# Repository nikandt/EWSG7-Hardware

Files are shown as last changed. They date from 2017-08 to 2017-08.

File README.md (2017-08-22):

# PP7 Hardware

This is the hardware repository of sensor probe test module, developed by student team with Aalto University.
<br>The designed system automates several tedious tasks within sensor application development by allowing easy flashing of devices without making physical changes to the test environment.

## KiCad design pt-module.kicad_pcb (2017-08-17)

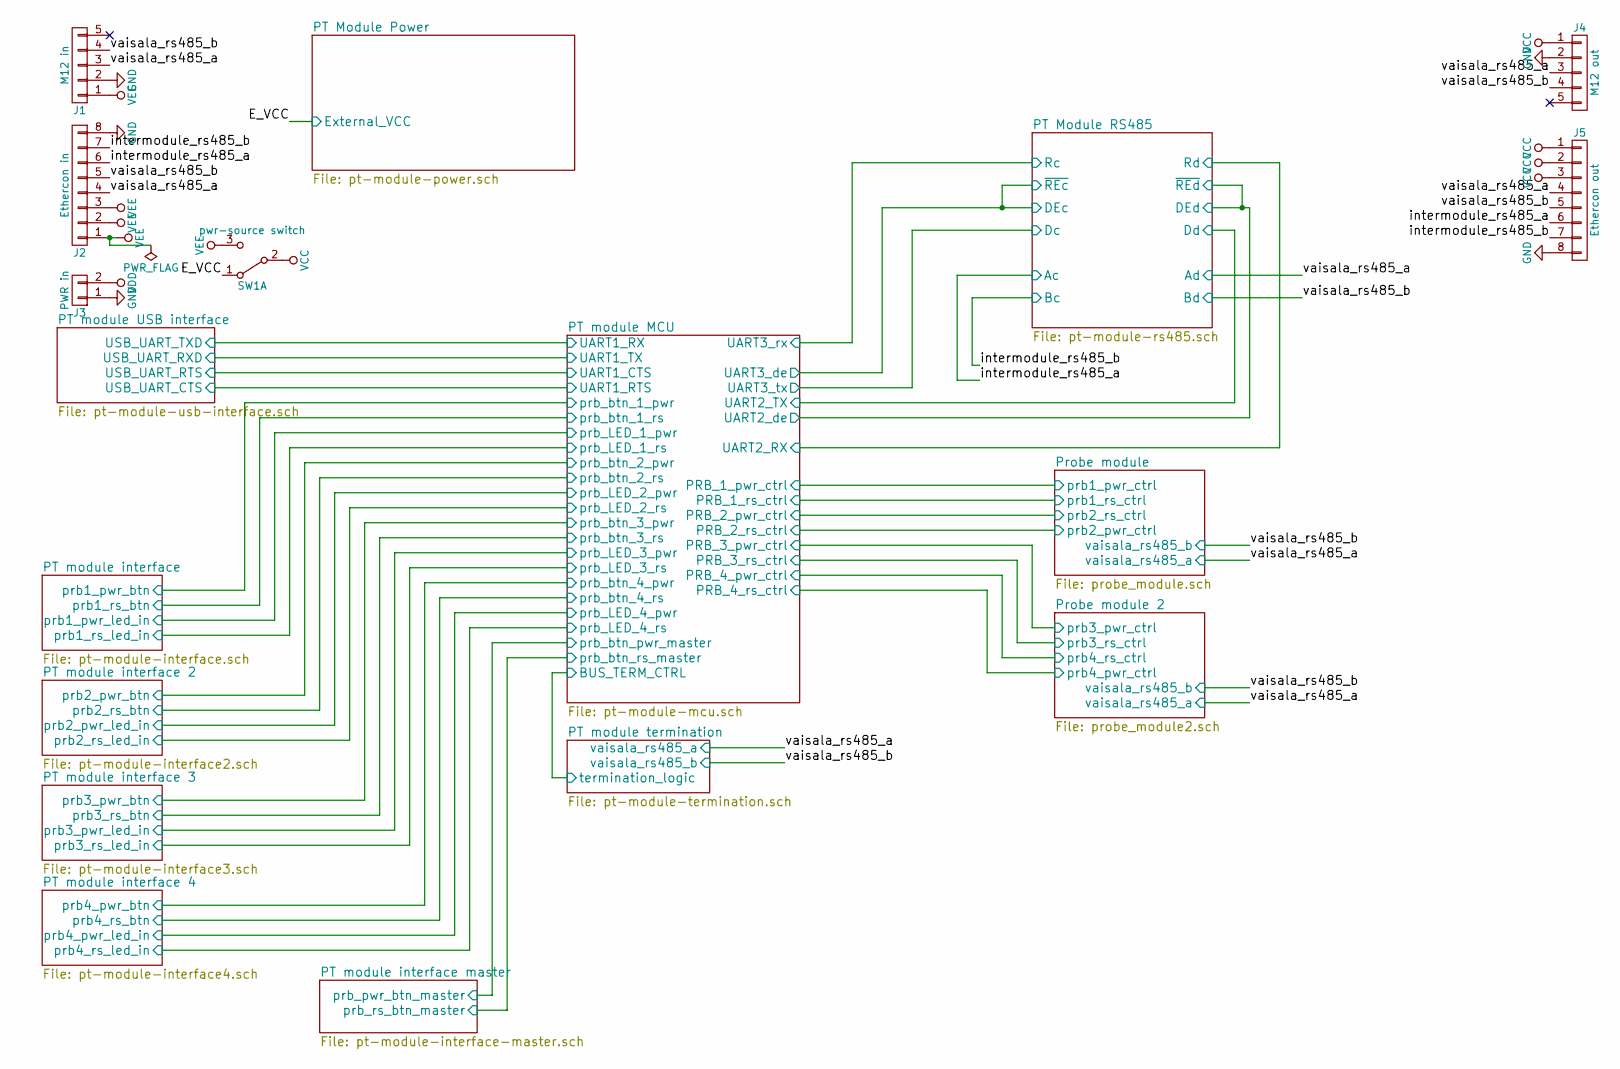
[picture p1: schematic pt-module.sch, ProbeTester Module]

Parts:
J1: M12 in; Hirose_DF13C-05P-1.25V_05x1.25mm_Straight
J2: Ethercon in; Hirose_DF13C-08P-1.25V_08x1.25mm_Straight
J3: PWR in; Hirose_DF13C-02P-1.25V_02x1.25mm_Straight
J4: M12 out; Hirose_DF13C-05P-1.25V_05x1.25mm_Straight
J5: Ethercon out; Hirose_DF13C-08P-1.25V_08x1.25mm_Straight
SW1: pwr-source switch; Hirose_DF13C-03P-1.25V_03x1.25mm_Straight

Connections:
/E_VCC: SW1.1 (A); also elsewhere on the board
/intermodule_rs485_a: J2.6, J5.6; also elsewhere on the board
/intermodule_rs485_b: J2.7, J5.7; also elsewhere on the board
/vaisala_rs485_a: J1.3, J2.4, J4.3, J5.4; also elsewhere on the board
/vaisala_rs485_b: J1.4, J2.5, J4.4, J5.5; also elsewhere on the board
GND: J1.2, J2.8, J3.1, J4.2, J5.8; also elsewhere on the board
VCC: J4.1, J5.1, J5.2, J5.3, SW1.2 (B); also elsewhere on the board
VDD: J3.2; also elsewhere on the board
VEE: J1.1, J2.1, J2.2, J2.3, SW1.3 (C)

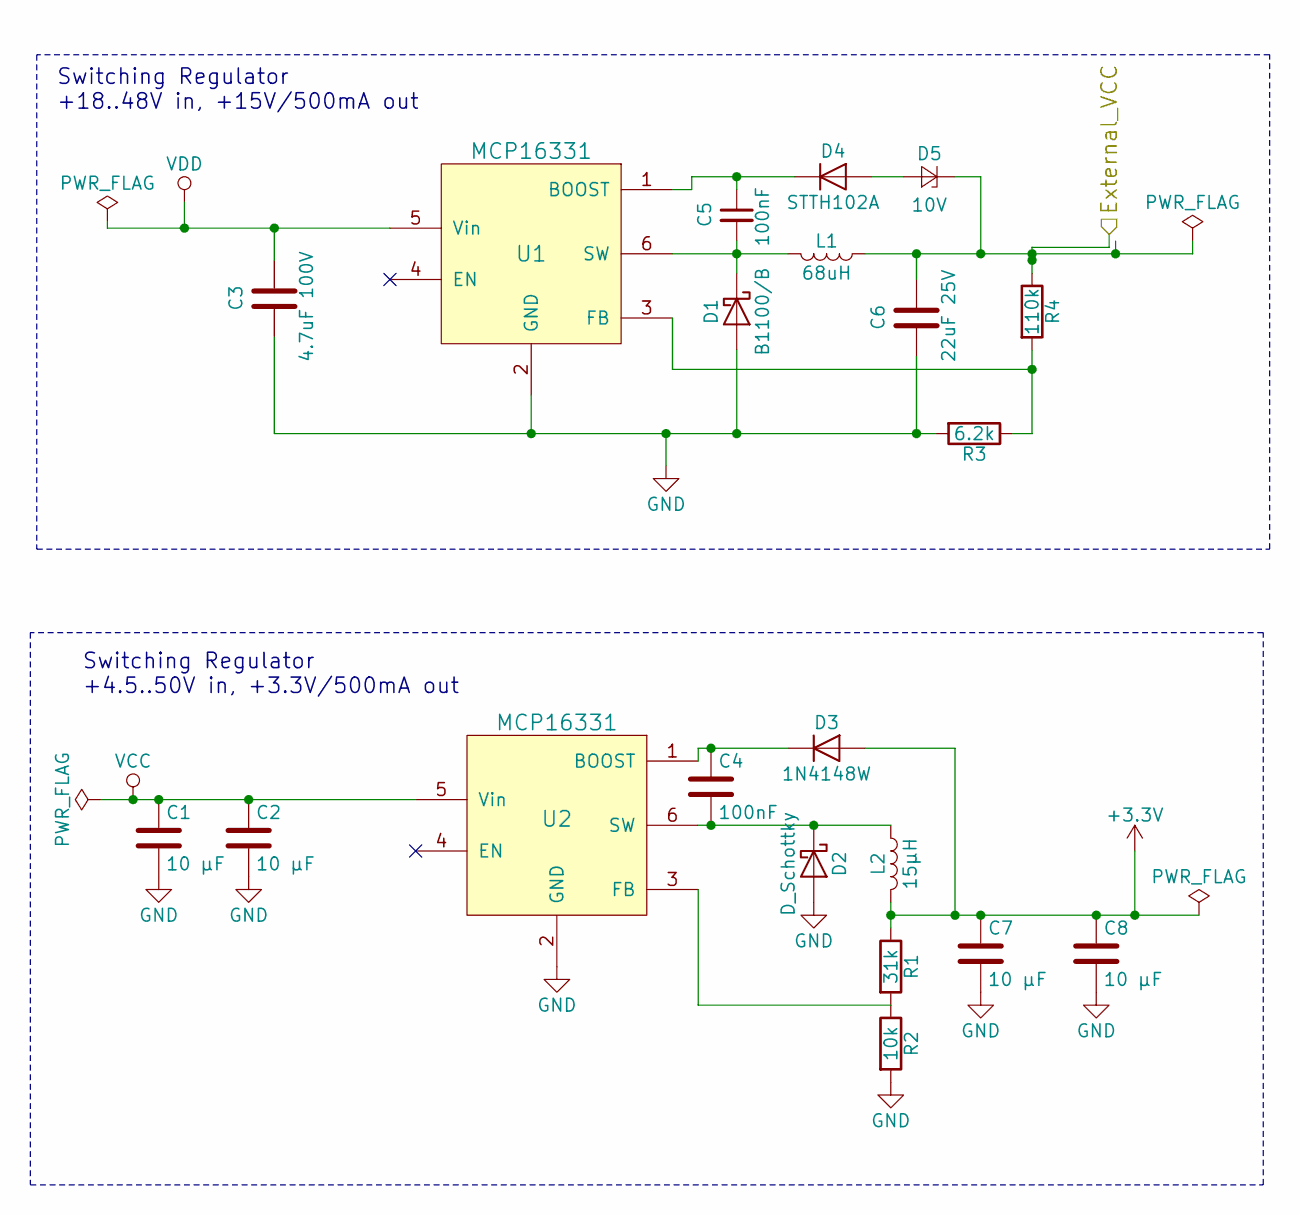
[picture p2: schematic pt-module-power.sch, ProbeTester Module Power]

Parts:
C1, C2, C7, C8: 10 µF; C_1206_HandSoldering
C3: 4.7uF 100V; C_1206_HandSoldering
C4, C5: 100nF; C_1206_HandSoldering
C6: 22uF 25V; C_1206_HandSoldering
D1: B1100/B; D_SMB
D2: D_Schottky; D_SMA
D3: 1N4148W; D_SOD-123F
D4: STTH102A; D_SMA
D5: 10V; D_SOD-323
L1: 68uH; L_7.3x7.3_H4.5
L2: 15µH; SM-4.3x4.3
R1: 31k; R_1206_HandSoldering
R2: 10k; R_1206_HandSoldering
R3: 6.2k; R_1206_HandSoldering
R4: 110k; R_1206_HandSoldering
U1, U2: MCP16331; SOT-23-6

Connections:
/E_VCC: C6.1, D5.1 (K), L1.1, R4.1; also elsewhere on the board
GND: C1.2, C2.2, C3.2, C6.2, C7.2, C8.2, D1.2 (A), D2.2 (A), R2.2, R3.2, U1.2 (GND), U2.2 (GND); also elsewhere on the board
unnamed: C4.1, D3.1 (K), U2.1 (BOOST)
unnamed: C4.2, D2.1 (K), L2.1, U2.6 (SW)
unnamed: C5.1, D4.1 (K), U1.1 (BOOST)
unnamed: C5.2, D1.1 (K), L1.2, U1.6 (SW)
unnamed: D4.2 (A), D5.2 (A)
unnamed: R1.2, R2.1, U2.3 (FB)
unnamed: R3.1, R4.2, U1.3 (FB)
VCC: C1.1, C2.1, U2.5 (Vin); also elsewhere on the board
VDD: C3.1, U1.5 (Vin); also elsewhere on the board

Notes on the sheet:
Switching Regulator +4.5..50V in, +3.3V/500mA out
Switching Regulator +18..48V in, +15V/500mA out

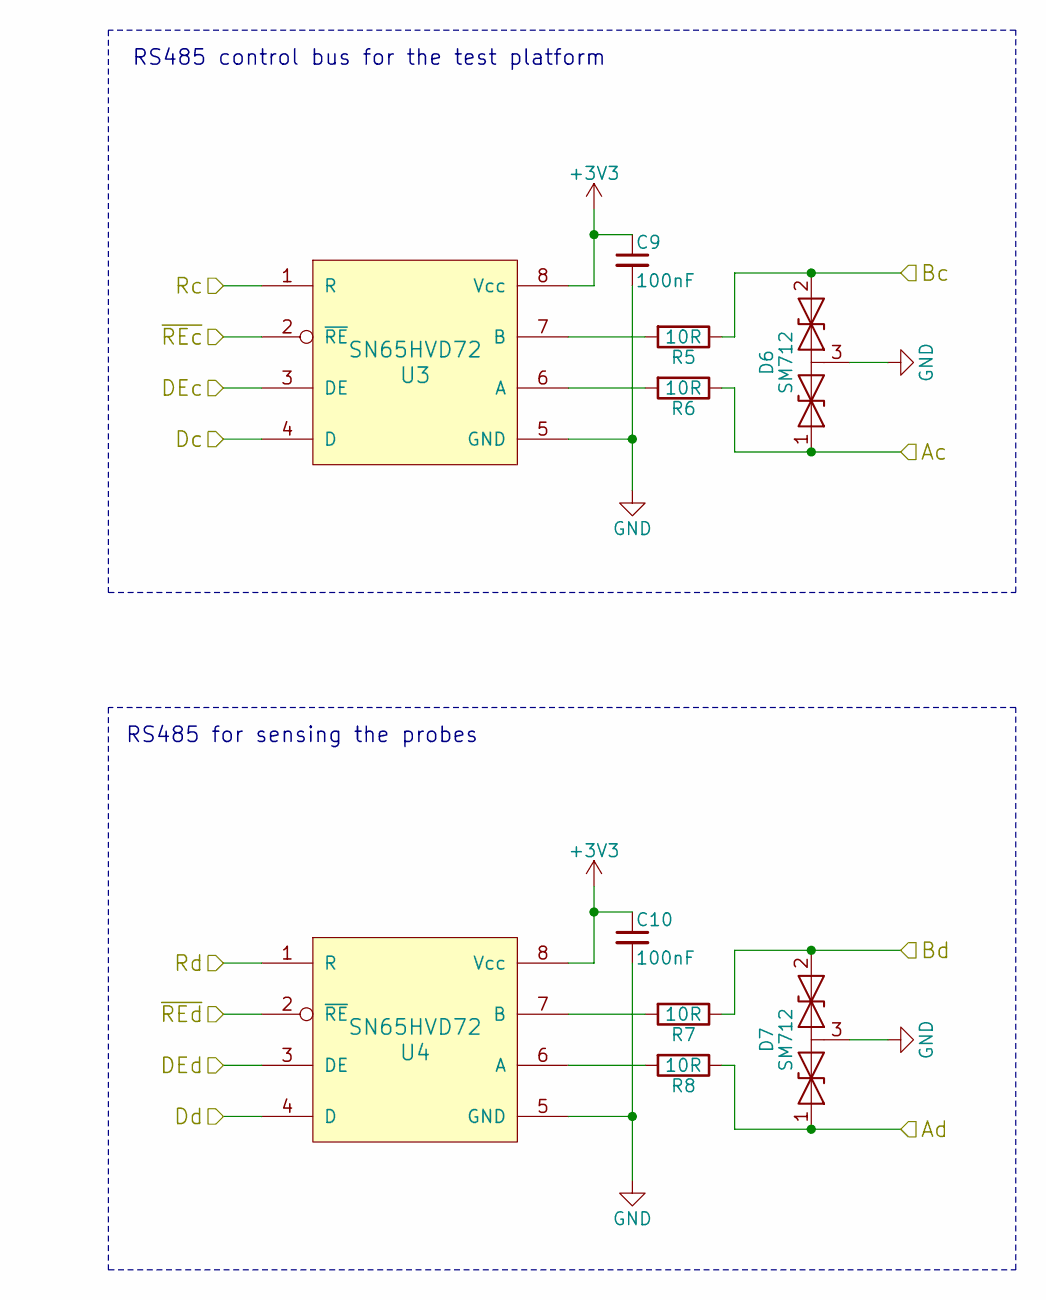
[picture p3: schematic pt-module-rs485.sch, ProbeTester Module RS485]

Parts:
C9, C10: 100nF; C_1206_HandSoldering
D6, D7: SM712; SOT-23_Handsoldering
R5, R6, R7, R8: 10R; R_0805_HandSoldering
U3, U4: SN65HVD72; SOIC-8_3.9x4.9mm_Pitch1.27mm

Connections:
/PT Module RS485/DEc: U3.2 (~RE), U3.3 (DE); also elsewhere on the board
/PT Module RS485/DEd: U4.2 (~RE), U4.3 (DE); also elsewhere on the board
/PT Module RS485/Dc: U3.4 (D); also elsewhere on the board
/PT Module RS485/Dd: U4.4 (D); also elsewhere on the board
/PT Module RS485/Rc: U3.1 (R); also elsewhere on the board
/PT Module RS485/Rd: U4.1 (R); also elsewhere on the board
/intermodule_rs485_a: D6.1 (A1), R6.1; also elsewhere on the board
/intermodule_rs485_b: D6.2 (A2), R5.1; also elsewhere on the board
/vaisala_rs485_a: D7.1 (A1), R8.1; also elsewhere on the board
/vaisala_rs485_b: D7.2 (A2), R7.1; also elsewhere on the board
GND: C9.2, C10.2, D6.3 (common), D7.3 (common), U3.5 (GND), U4.5 (GND); also elsewhere on the board
unnamed: R5.2, U3.7 (B)
unnamed: R6.2, U3.6 (A)
unnamed: R7.2, U4.7 (B)
unnamed: R8.2, U4.6 (A)

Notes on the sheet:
RS485 for sensing the probes
RS485 control bus for the test platform

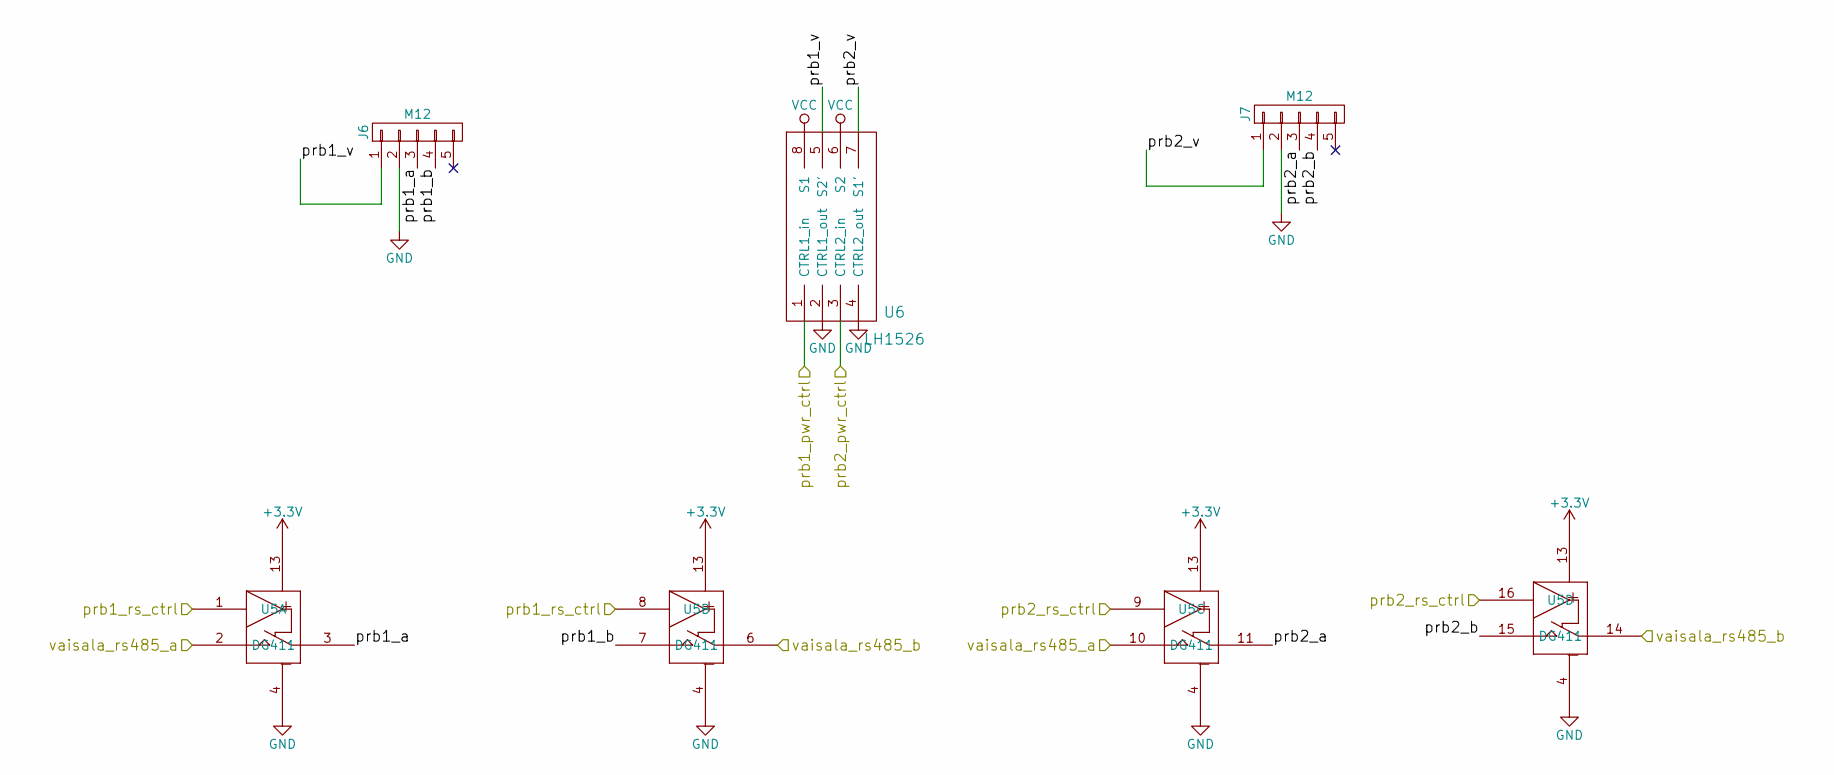
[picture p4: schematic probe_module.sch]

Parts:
J6, J7: M12; Hirose_DF13C-05P-1.25V_05x1.25mm_Straight
U5: DG411; DIP-16_W7.62mm_SMD
U6: LH1526; DIP-8_W9.53mm_SMD

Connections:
/PT module MCU/PRB_1_pwr_ctrl: U6.1 (CTRL1_in); also elsewhere on the board
/PT module MCU/PRB_1_rs_ctrl: U5.1 (SW), U5.8 (SW); also elsewhere on the board
/PT module MCU/PRB_2_pwr_ctrl: U5.9 (SW), U5.16 (SW); also elsewhere on the board
/PT module MCU/PRB_2_rs_ctrl: U6.3 (CTRL2_in); also elsewhere on the board
/Probe module/prb1_a: J6.3, U5.3 (OUT)
/Probe module/prb1_b: J6.4, U5.7 (IN)
/Probe module/prb1_v: J6.1, U6.5 (S2')
/Probe module/prb2_a: J7.3, U5.11 (OUT)
/Probe module/prb2_b: J7.4, U5.15 (IN)
/Probe module/prb2_v: J7.1, U6.7 (S1')
/vaisala_rs485_a: U5.2 (IN), U5.10 (IN); also elsewhere on the board
/vaisala_rs485_b: U5.6 (OUT), U5.14 (OUT); also elsewhere on the board
GND: J6.2, J7.2, U5.4 (V-), U5.5 (GND), U6.2 (CTRL1_out), U6.4 (CTRL2_out); also elsewhere on the board
VCC: U5.12 (VCC), U6.6 (S2), U6.8 (S1); also elsewhere on the board

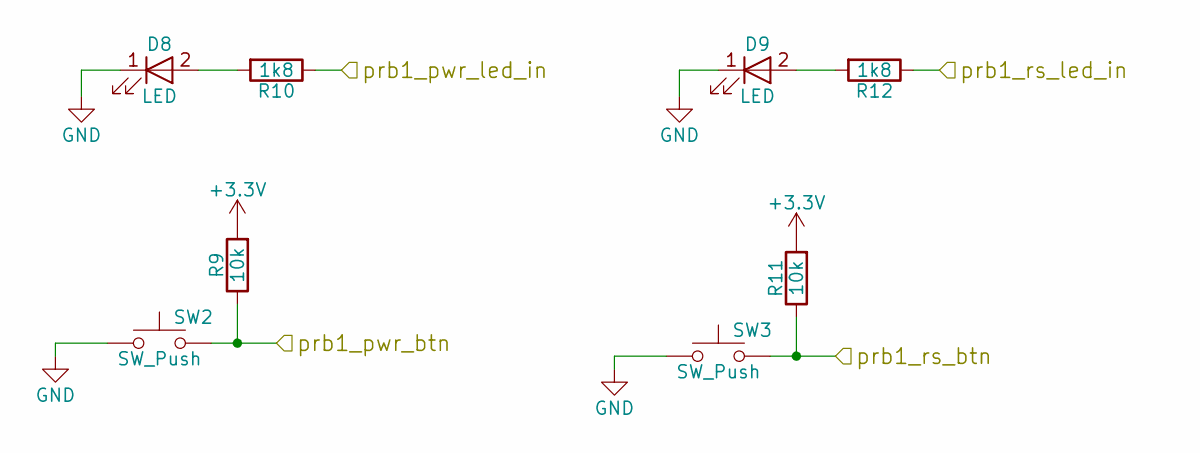
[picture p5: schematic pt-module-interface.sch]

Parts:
D8, D9: LED; Hirose_DF13C-02P-1.25V_02x1.25mm_Straight
R9, R11: 10k; R_1206_HandSoldering
R10, R12: 1k8; R_1206_HandSoldering
SW2, SW3: SW_Push; Hirose_DF13C-02P-1.25V_02x1.25mm_Straight

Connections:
/PT module interface/prb1_pwr_btn: R9.1, SW2.2; also elsewhere on the board
/PT module interface/prb1_pwr_led_in: R10.1; also elsewhere on the board
/PT module interface/prb1_rs_btn: R11.1, SW3.2; also elsewhere on the board
/PT module interface/prb1_rs_led_in: R12.1; also elsewhere on the board
GND: D8.1 (K), D9.1 (K), SW2.1, SW3.1; also elsewhere on the board
unnamed: D8.2 (A), R10.2
unnamed: D9.2 (A), R12.2

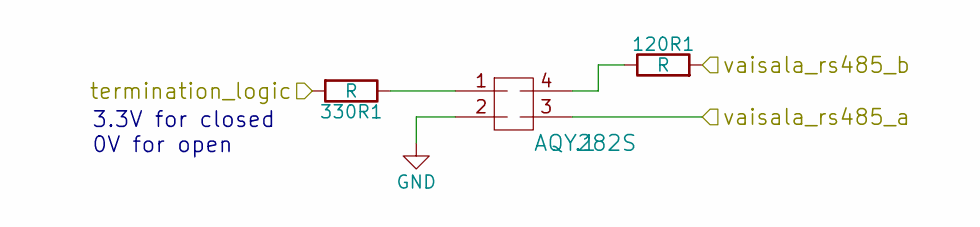
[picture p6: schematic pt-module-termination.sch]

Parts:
120R1: R; R_Axial_DIN0207_L6.3mm_D2.5mm_P7.62mm_Horizontal
330R1: R; R_1206_HandSoldering
.1: AQY282S; DIP-8_W11.48mm_SMD

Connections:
unnamed 57: 330R1.1, .1.1; also elsewhere on the board
unnamed 58: 120R1.1, .1.4; also elsewhere on the board

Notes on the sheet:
3.3V for closed 0V for open

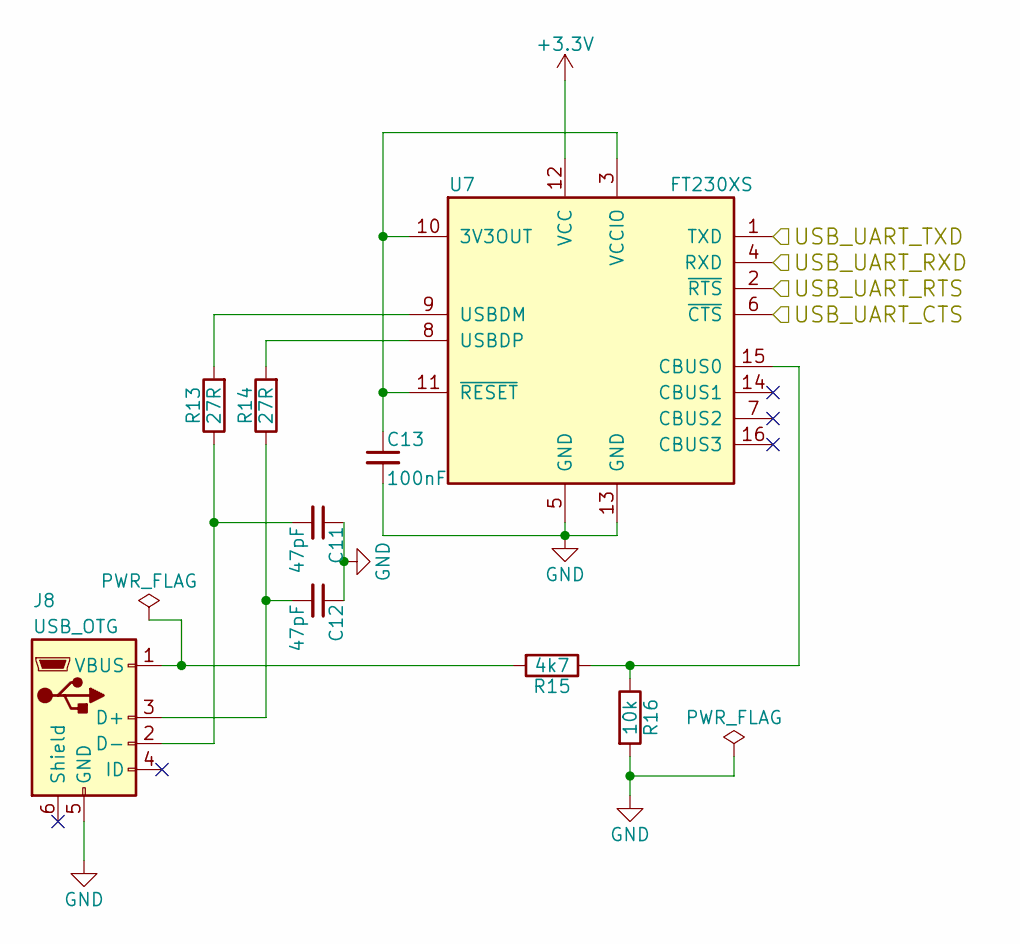
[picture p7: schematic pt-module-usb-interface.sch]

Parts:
C11, C12: 47pF; C_1206_HandSoldering
C13: 100nF; C_1206_HandSoldering
J8: USB_OTG; Hirose_DF13C-06P-1.25V_06x1.25mm_Straight
R13, R14: 27R; R_1206_HandSoldering
R15: 4k7; R_1206_HandSoldering
R16: 10k; R_1206_HandSoldering
U7: FT230XS; SSOP-16_3.9x4.9mm_Pitch0.635mm

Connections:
/PT module MCU/UART1_CTS: U7.2 (~RTS); also elsewhere on the board
/PT module MCU/UART1_RTS: U7.6 (~CTS); also elsewhere on the board
/PT module MCU/UART1_RX: U7.1 (TXD); also elsewhere on the board
/PT module MCU/UART1_TX: U7.4 (RXD); also elsewhere on the board
GND: C11.1, C12.1, C13.2, J8.5 (GND), R16.2, U7.5 (GND), U7.13 (GND); also elsewhere on the board
unnamed: C11.2, J8.2 (D-), R13.1
unnamed: C12.2, J8.3 (D+), R14.1
unnamed: C13.1, U7.3 (VCCIO), U7.10 (3V3OUT), U7.11 (~RESET)
unnamed: J8.1 (VBUS), R15.2
unnamed: R13.2, U7.9 (USBDM)
unnamed: R14.2, U7.8 (USBDP)
unnamed: R15.1, R16.1, U7.15 (CBUS0)

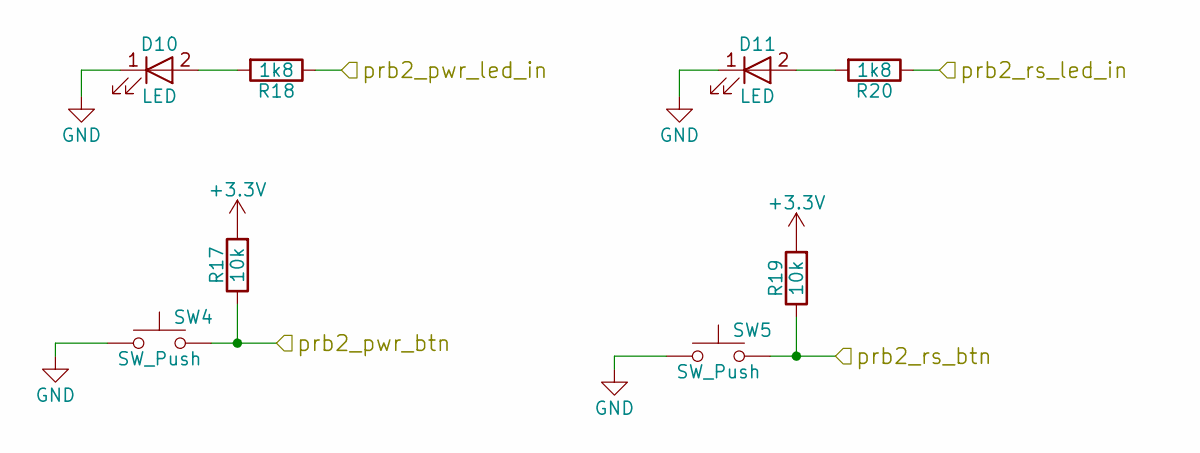
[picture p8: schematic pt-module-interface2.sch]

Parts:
D10, D11: LED; Hirose_DF13C-02P-1.25V_02x1.25mm_Straight
R17, R19: 10k; R_1206_HandSoldering
R18, R20: 1k8; R_1206_HandSoldering
SW4, SW5: SW_Push; Hirose_DF13C-02P-1.25V_02x1.25mm_Straight

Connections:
/PT module interface 2/prb2_pwr_btn: R17.1, SW4.2; also elsewhere on the board
/PT module interface 2/prb2_pwr_led_in: R18.1; also elsewhere on the board
/PT module interface 2/prb2_rs_btn: R19.1, SW5.2; also elsewhere on the board
/PT module interface 2/prb2_rs_led_in: R20.1; also elsewhere on the board
GND: D10.1 (K), D11.1 (K), SW4.1, SW5.1; also elsewhere on the board
unnamed: D10.2 (A), R18.2
unnamed: D11.2 (A), R20.2

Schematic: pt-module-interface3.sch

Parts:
D12, D13: LED; Hirose_DF13C-02P-1.25V_02x1.25mm_Straight
R21, R23: 10k; R_1206_HandSoldering
R22, R24: 1k8; R_1206_HandSoldering
SW6, SW7: SW_Push; Hirose_DF13C-02P-1.25V_02x1.25mm_Straight

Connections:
/PT module interface 3/prb3_pwr_btn: R21.1, SW6.2; also elsewhere on the board
/PT module interface 3/prb3_pwr_led_in: R22.1; also elsewhere on the board
/PT module interface 3/prb3_rs_btn: R23.1, SW7.2; also elsewhere on the board
/PT module interface 3/prb3_rs_led_in: R24.1; also elsewhere on the board
GND: D12.1 (K), D13.1 (K), SW6.1, SW7.1; also elsewhere on the board
unnamed: D12.2 (A), R22.2
unnamed: D13.2 (A), R24.2

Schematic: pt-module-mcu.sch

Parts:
16Mhz1: Crystal; HC49_Crystal
C14, C15: 27pF; C_1206_HandSoldering
C16, C17, C18, C19, C20, C21: C_Small; C_1206_HandSoldering
R25, R26: 10k; R_1206_HandSoldering
SW8, SW9: SW_Push; Hirose_DF13C-02P-1.25V_02x1.25mm_Straight
U8: STM32F334R8Tx; LQFP-64_10x10mm_Pitch0.5mm

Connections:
/PT Module RS485/DEc: U8.35 (ADC2_IN14/HRTIM1_CHD1/OPAMP2_VINP/OPAMP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); also elsewhere on the board
/PT Module RS485/DEd: U8.15 (ADC1_IN2/RTC_REFIN/TIM15_CH1N/TIM2_CH2/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); also elsewhere on the board
/PT Module RS485/Dc: U8.62 (CAN_TX/COMP2_OUT/DAC1_EXTI9/DAC2_EXTI9/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); also elsewhere on the board
/PT Module RS485/Dd: U8.16 (ADC1_IN3/COMP2_INM/COMP2_OUT/TIM15_CH1/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); also elsewhere on the board
/PT Module RS485/Rc: U8.61 (CAN_RX/HRTIM1_EEV8/I2C1_SCL/TIM16_CH1/T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); also elsewhere on the board
/PT Module RS485/Rd: U8.17 (ADC1_IN4/TIM15_CH2/TIM2_CH4/TSC_G1_IO4/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); also elsewhere on the board
/PT module MCU/BUS_TERM_CTRL: U8.36 (ADC2_IN15/COMP6_INM/HRTIM1_CHD2/RTC_REF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); also elsewhere on the board
/PT module MCU/PRB_1_pwr_ctrl: U8.22 (ADC2_IN3/DAC2_OUT1/OPAMP2_DIG/OPAMP2_VO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); also elsewhere on the board
/PT module MCU/PRB_1_rs_ctrl: U8.23 (ADC2_IN4/COMP2_INP/OPAMP2_VINP/OPAMP2_V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); also elsewhere on the board
/PT module MCU/PRB_2_pwr_ctrl: U8.41 (HRTIM1_CHA1/RCC_MCO/TIM1_CH1/USART1_CK/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); also elsewhere on the board
/PT module MCU/PRB_2_rs_ctrl: U8.42 (DAC1_EXTI9/DAC2_EXTI9/HRTIM1_CHA2/TIM15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); also elsewhere on the board
/PT module MCU/PRB_3_pwr_ctrl: U8.26 (ADC1_IN11/COMP4_INP/OPAMP2_VINP/OPAMP2_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); also elsewhere on the board
/PT module MCU/PRB_3_rs_ctrl: U8.27 (ADC1_IN12/COMP4_OUT/HRTIM1_SCOUT/TIM1_C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); also elsewhere on the board
/PT module MCU/PRB_4_pwr_ctrl: U8.28 (ADC2_IN12/COMP4_INM/HRTIM1_SCIN/TSC_G3_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); also elsewhere on the board
/PT module MCU/PRB_4_rs_ctrl: U8.55 (HRTIM1_EEV9/HRTIM1_SCOUT/SPI1_SCK/SYS_J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); also elsewhere on the board
/PT module MCU/RCC_OSC_IN: 16Mhz1.1, C14.1, U8.5 (PF0/RCC_OSC_IN/TIM1_CH3N)
/PT module MCU/RCC_OSC_OUT: 16Mhz1.2, C15.1, U8.6 (PF1/RCC_OSC_OUT)
/PT module MCU/UART1_CTS: U8.44 (CAN_RX/HRTIM1_CHB2/TIM1_BKIN2/TIM1_CH1N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); also elsewhere on the board
/PT module MCU/UART1_RTS: U8.45 (CAN_TX/COMP2_OUT/HRTIM1_FLT1/TIM16_CH1/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); also elsewhere on the board
/PT module MCU/UART1_RX: U8.59 (HRTIM1_EEV3/I2C1_SDA/TIM17_CH1N/TIM3_CH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); also elsewhere on the board
/PT module MCU/UART1_TX: U8.58 (HRTIM1_EEV4/HRTIM1_SCIN/I2C1_SCL/TIM16_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); also elsewhere on the board
/PT module MCU/prb_btn_pwr_master: U8.20 (ADC2_IN1/COMP2_INM/COMP4_INM/COMP6_INM/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); also elsewhere on the board
/PT module MCU/prb_btn_rs_master: U8.21 (ADC2_IN2/DAC1_OUT2/OPAMP2_VINM/OPAMP2_V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); also elsewhere on the board
/PT module interface 2/prb2_pwr_btn: U8.24 (PC4/ADC2_IN5/TIM1_ETR/USART1_TX); also elsewhere on the board
/PT module interface 2/prb2_pwr_led_in: U8.37 (PC6/COMP6_OUT/HRTIM1_EEV10/TIM3_CH1); also elsewhere on the board
/PT module interface 2/prb2_rs_btn: U8.25 (PC5/ADC2_IN11/OPAMP2_VINM/OPAMP2_VINM_S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); also elsewhere on the board
/PT module interface 2/prb2_rs_led_in: U8.38 (PC7/HRTIM1_FLT5/TIM3_CH2); also elsewhere on the board
/PT module interface 3/prb3_pwr_btn: U8.39 (PC8/HRTIM1_CHE1/TIM3_CH3); also elsewhere on the board
/PT module interface 3/prb3_pwr_led_in: U8.51 (PC10/USART3_TX); also elsewhere on the board
/PT module interface 3/prb3_rs_btn: U8.40 (PC9/DAC1_EXTI9/DAC2_EXTI9/HRTIM1_CHE2/T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); also elsewhere on the board
/PT module interface 3/prb3_rs_led_in: U8.52 (PC11/HRTIM1_EEV2/USART3_RX); also elsewhere on the board
/PT module interface 4/prb4_pwr_btn: U8.53 (PC12/HRTIM1_EEV1/USART3_CK); also elsewhere on the board
/PT module interface 4/prb4_pwr_led_in: U8.3 (PC14/RCC_OSC32_IN); also elsewhere on the board
/PT module interface 4/prb4_rs_btn: U8.2 (PC13/RTC_OUT_ALARM/RTC_OUT_CALIB/RTC_TA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); also elsewhere on the board
/PT module interface 4/prb4_rs_led_in: U8.4 (PC15/RCC_OSC32_OUT); also elsewhere on the board
/PT module interface/prb1_pwr_btn: U8.8 (PC0/ADC1_IN6/ADC2_IN6/TIM1_CH1); also elsewhere on the board
/PT module interface/prb1_pwr_led_in: U8.10 (PC2/ADC1_IN8/ADC2_IN8/TIM1_CH3); also elsewhere on the board
/PT module interface/prb1_rs_btn: U8.9 (PC1/ADC1_IN7/ADC2_IN7/TIM1_CH2); also elsewhere on the board
/PT module interface/prb1_rs_led_in: U8.11 (PC3/ADC1_IN9/ADC2_IN9/TIM1_BKIN2/TIM1_C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); also elsewhere on the board
GND: C14.2, C15.2, C16.1, C17.1, C18.1, C19.1, C20.1, C21.1, R25.1, SW9.1, U8.12 (VSSA), U8.18 (VSS), U8.31 (VSS), U8.47 (VSS), U8.63 (VSS); also elsewhere on the board
unnamed: R25.2, SW8.2, U8.60 (BOOT0)
unnamed: R26.2, SW9.2, U8.7 (NRST)

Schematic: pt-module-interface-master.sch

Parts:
R27, R28: 10k; R_1206_HandSoldering
SW10, SW11: SW_Push; Hirose_DF13C-02P-1.25V_02x1.25mm_Straight

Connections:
/PT module MCU/prb_btn_pwr_master: R27.2, SW10.2; also elsewhere on the board
/PT module MCU/prb_btn_rs_master: R28.2, SW11.2; also elsewhere on the board
GND: SW10.1, SW11.1; also elsewhere on the board

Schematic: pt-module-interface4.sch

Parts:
D14, D15: LED; Hirose_DF13C-02P-1.25V_02x1.25mm_Straight
R29, R31: 10k; R_1206_HandSoldering
R30, R32: 1k8; R_1206_HandSoldering
SW12, SW13: SW_Push; Hirose_DF13C-02P-1.25V_02x1.25mm_Straight

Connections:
/PT module interface 4/prb4_pwr_btn: R29.1, SW12.2; also elsewhere on the board
/PT module interface 4/prb4_pwr_led_in: R30.1; also elsewhere on the board
/PT module interface 4/prb4_rs_btn: R31.1, SW13.2; also elsewhere on the board
/PT module interface 4/prb4_rs_led_in: R32.1; also elsewhere on the board
GND: D14.1 (K), D15.1 (K), SW12.1, SW13.1; also elsewhere on the board
unnamed: D14.2 (A), R30.2
unnamed: D15.2 (A), R32.2

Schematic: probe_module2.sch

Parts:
J9, J10: M12; Hirose_DF13C-05P-1.25V_05x1.25mm_Straight
U9: DG411; DIP-16_W7.62mm_SMD
U10: LH1526; DIP-8_W9.53mm_SMD

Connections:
/PT module MCU/PRB_3_pwr_ctrl: U10.1 (CTRL1_in); also elsewhere on the board
/PT module MCU/PRB_3_rs_ctrl: U9.1 (SW), U9.8 (SW); also elsewhere on the board
/PT module MCU/PRB_4_pwr_ctrl: U9.9 (SW), U9.16 (SW); also elsewhere on the board
/PT module MCU/PRB_4_rs_ctrl: U10.3 (CTRL2_in); also elsewhere on the board
/Probe module 2/prb1_a: J9.3, U9.3 (OUT)
/Probe module 2/prb1_b: J9.4, U9.7 (IN)
/Probe module 2/prb1_v: J9.1, U10.5 (S2')
/Probe module 2/prb2_a: J10.3, U9.11 (OUT)
/Probe module 2/prb2_b: J10.4, U9.15 (IN)
/Probe module 2/prb2_v: J10.1, U10.7 (S1')
/vaisala_rs485_a: U9.2 (IN), U9.10 (IN); also elsewhere on the board
/vaisala_rs485_b: U9.6 (OUT), U9.14 (OUT); also elsewhere on the board
GND: J9.2, J10.2, U9.4 (V-), U9.5 (GND), U10.2 (CTRL1_out), U10.4 (CTRL2_out); also elsewhere on the board
VCC: U9.12 (VCC), U10.6 (S2), U10.8 (S1); also elsewhere on the board

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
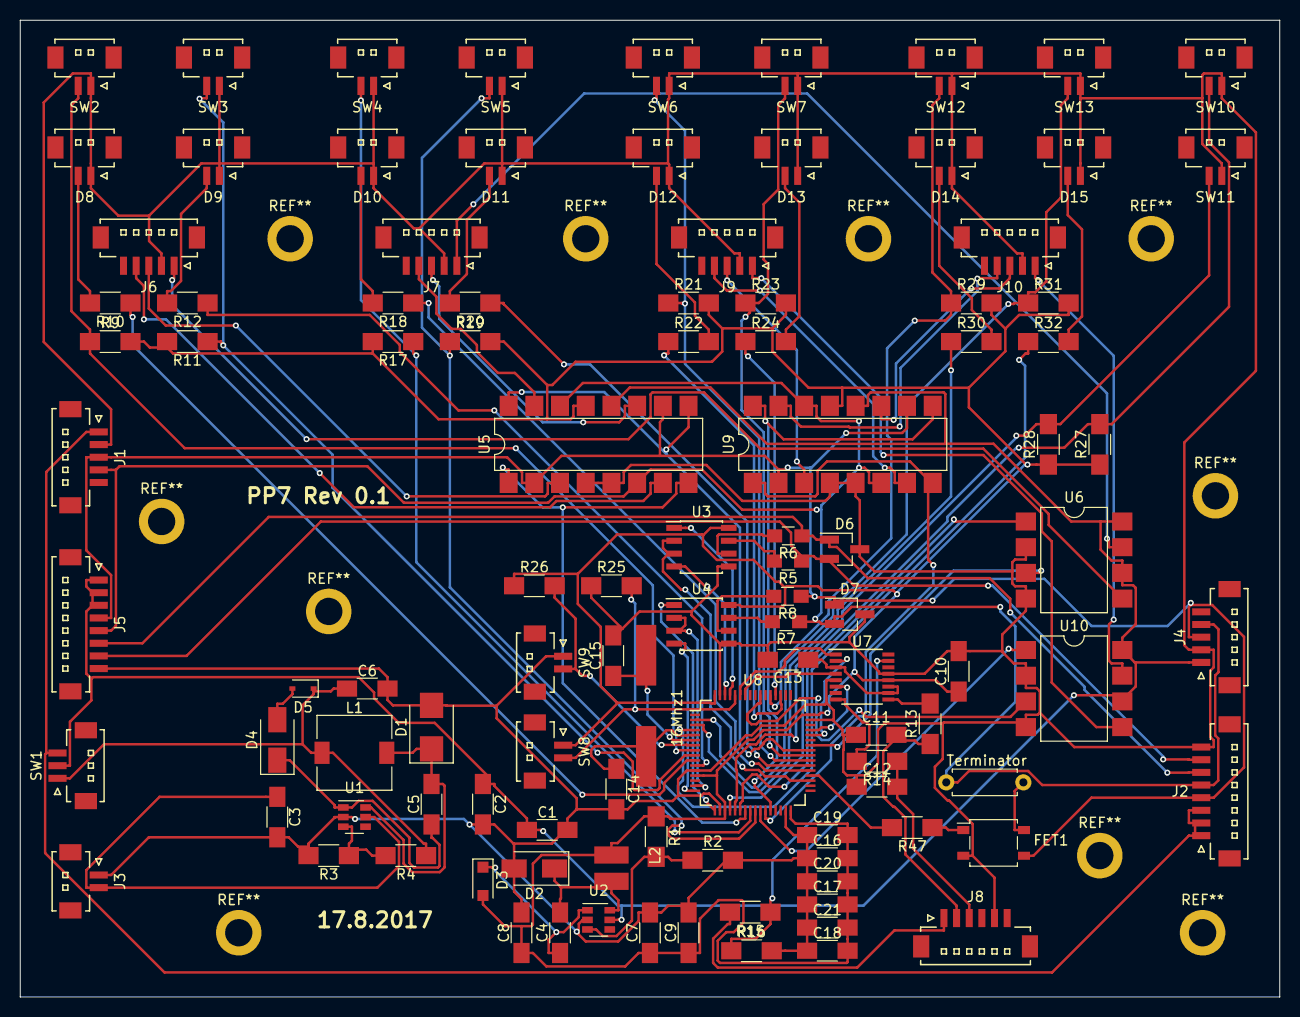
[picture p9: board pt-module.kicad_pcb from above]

Board: 2 copper layers, 124.5 x 96.5 mm, 107 parts (0 on the bottom side), 91 nets.

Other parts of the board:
FET1: AQY282S; SO-4_4.4x4.3mm_Pitch2.54mm
R47: 330R; R_1206_HandSoldering
Terminator: R; R_Axial_DIN0207_L6.3mm_D2.5mm_P7.62mm_Horizontal

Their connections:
/PT module MCU/BUS_TERM_CTRL: R47.2; also elsewhere on the board
/vaisala_rs485_a: FET1.3; also elsewhere on the board
/vaisala_rs485_b: Terminator.2; also elsewhere on the board
GND: FET1.2; also elsewhere on the board
unnamed 57: FET1.1, R47.1; also elsewhere on the board
unnamed 58: FET1.4, Terminator.1; also elsewhere on the board

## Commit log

2017-07-28 add power schematic
    [pt-module-power.sch, pt-module.kicad_pcb, pt-module.sch]
2017-07-29 add rs485 schematic
    [pt-module-rs485.sch, pt-module.sch]
2017-08-02 MCU schematics added
    [pt-module-mcu.sch, pt-module-power.sch, pt-module-rs485.sch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]
2017-08-02 add probe module
    [probe_module.sch, pt-module-mcu.sch, pt-module-power.sch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]
2017-08-02 add interface module
    [probe_module.sch, pt-module-interface.sch, pt-module-mcu.sch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]
2017-08-02 add vaisala bus
    [probe_module.sch, pt-module.sch]
2017-08-02 add connectors
    [pt-module.sch]
2017-08-02 add power connections
    [pt-module-power.sch, pt-module.sch]
2017-08-03 add termination
    [probe_module.sch, pt-module-interface.sch, pt-module-mcu.sch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]
2017-08-03 Added USB to UART interface
    [probe_module.sch, pt-module-interface.sch, pt-module-mcu.sch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]
2017-08-03 Added USB UART hierarchical connection
    [pt-module-mcu.sch, pt-module.sch]
2017-08-03 Added another rs485 link to MCU
    [pt-module-mcu.sch, pt-module.sch]
2017-08-03 add resistor values
    [pt-module-interface.sch, pt-module-termination.sch, pt-module.sch]
2017-08-03 Added resistor and capacitor values in MCU sheet.
    [pt-module-interface.sch, pt-module-mcu.sch, pt-module-termination.sch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]
2017-08-04 Fixed vusb_sense connection mistake
    [pt-module-usb-interface.sch]
2017-08-08 add regulator suggestion
    [pt-module-power.sch]
2017-08-08 add capacitor values
    [pt-module-power.sch]
2017-08-08 I made a connect
    [pt-module-interface-master.sch, pt-module-mcu.sch, pt-module-usb-interface.sch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]
2017-08-08 indeces to interfacemodules
    [pt-module-power.sch, pt-module.sch]
2017-08-08 I don't know what I did
    [probe_module.sch, pt-module-interface.sch, pt-module-mcu.sch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]
2017-08-08 add libraries
    [probe_module.sch, pt-module-interface-master.sch, pt-module-interface.sch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]
2017-08-08 add ssr component
    [probe_module.sch, pt-module-interface-master.sch, pt-module-interface.sch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]
2017-08-08 change probe powerswitch to ssr
    [probe_module.sch, pt-module-interface-master.sch, pt-module-interface.sch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]
2017-08-08 multiply probe modules
    [pt-module.sch]
2017-08-09 add termination switch
    [probe_module.sch, pt-module-interface-master.sch, pt-module-interface.sch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]
2017-08-15 Fixed missing components
    [probe_module.sch, pt-module-interface-master.sch, pt-module-interface.sch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]
2017-08-15 Connected EVERYTHING. Ran ERC. There are still some power errors.
    [probe_module2.sch, pt-module-interface-master.sch, pt-module-interface2.sch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]
2017-08-16 fix power scheme
    [pt-module-power.sch]
2017-08-16 USB interface fix
    [pt-module-usb-interface.sch]
2017-08-16 Added power flags and ERC error count shrinked into 3.
    [probe_module.sch, probe_module2.sch, pt-module-interface-master.sch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]
2017-08-16 Only 1 error in ERC check. It's in PWREN.
    [probe_module.sch, probe_module2.sch, pt-module-interface-master.sch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]
2017-08-16 Determined MCU power capacitor sizes, at last
    [probe_module.sch, probe_module2.sch, pt-module-interface-master.sch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]
2017-08-16 add footprints
    [_saved_probe_module.sch, _saved_probe_module2.sch, _saved_pt-module-power.sch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]
2017-08-17 add all the rest of the footprints
    [_saved_probe_module.sch, _saved_probe_module2.sch, _saved_pt-module-power.sch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]
2017-08-17 fix footprint errors
    [probe_module.sch, probe_module2.sch, pt-module-rs485.sch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]
2017-08-17 start the pcb
    [pt-module-mcu.sch, pt-module-usb-interface.sch, pt-module.kicad_pcb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]
2017-08-17 pcb design
    [pt-module.kicad_pcb]
2017-08-17 Updated PCB
    [pt-module.kicad_pcb]
2017-08-17 bug fix
    [pt-module.kicad_pcb]
2017-08-17 add connections
    [pt-module.kicad_pcb]
2017-08-17 make gerbers
    [pt-module.kicad_pcb]
